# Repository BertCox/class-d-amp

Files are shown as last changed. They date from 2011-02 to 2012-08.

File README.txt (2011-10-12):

File: README.txt
Description: Project-specific instructions and information concerning files
    located within this hierarchy and subhierarchies. In the event of
    conflicts, the lowest-level README.txt file is used for information
    regarding a file or files.

Current Location: ClassDAmp/

Description:
    The Class-D Audio amplifier is an audio amplifier based on the 2004 Sorensen
audio amplifier design (http://listen.to/audioexperiment). The amplifier is able
to provide 100 watts RMS power spread across 2 stereo channels (50 watts RMS each)

Contents:
    Included in this repository are the source files and documentation
necessary to recreate the Class-D audio amplifier. If you believe something is 
missing from the project, please contact us at http://nbitwonder.com/blog/contact

Documentation:
    Documentation related to this project is included in the 'Documentation'
folder. For additional documentation and other information, please see:
http://nbitwonder.com/blog/projects/class-d-audio-amp/

License Information:
    NBitWonder projects are released under the GNU GPL v3.0 for software,
firmware, simulations, and documentation and Creative Commons CC-BY-3.0 
for electronics and mechanical components. License copies can be found in the
file 'license.txt' in each of these top-level folders.
    NBitWonder projects may use files, software, libraries, etc. which is not
open source. These components may not be distributed within the project
repository or use a different license than that specified in license.txt. In
these cases, acquisition instructions and license exceptions are noted in a
given hierarchy's 'README.txt' file. Where conflicting, the lowest-level
'README.txt' file shall apply to a given file or files.

Ben Laskowski
Chief Technical Officer
NBitWonder, LLC

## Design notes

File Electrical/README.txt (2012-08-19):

File: README.txt
Description: Project-specific instructions and information concerning files
    located within this hierarchy and subhierarchies. In the event of
    conflicts, the lowest-level README.txt file is used for information
    regarding a file or files.

Current Location: ClassDAmp/Electrical

Notes:
    This directory contains the following files:
    Version 3.0:
	* single-supply-bridged schematic and layout: The most recent version of 	  the circuit, and the only supported version.
    Version 2.0:
        * single-supply-bridged schematic and layout: 50W max output, questionable 	  speaker protection circuit
    Version 1.0:    
        * class-d-amp-single-supply schematic and pcb: An untested lower-output
          version, appx. 15W per channel
        * class-d-amp-3-5-mm sch/pcb: A dual-supply version, 25W per channel max.
          Not recommended for construction.
        * class-d-amp sch/pcb: The original board layout. Self-destructed during
          first test. Do not build.

Software:
    All electronic design files were created using EagleCAD v5.11 from CADSoft. 
A freeware copy of this software, as well as additional information about this 
software, can be found at http://www.cadsoftusa.com/

License:
    All electronic CAD design files contained within this hierarchy, except those
noted in the 'Exceptions' section below, are made publicly available via a 
Creative-Commons CC-BY-SA 3.0 license. For more information on the license, see 
http://creativecommons.org/licenses/by-sa/3.0/
    Additionally, a complete copy of the license text can be found in the file
'license.txt' distributed within this folder.

Exceptions:
    The following alternative licensing requirements apply to the following files:

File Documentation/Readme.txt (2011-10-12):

File: README.txt
Description: Project-specific instructions and information concerning files
    located within this hierarchy and subhierarchies. In the event of
    conflicts, the lowest-level README.txt file is used for information
    regarding a file or files.
            
Current Location: ClassDAmp/Documentation

    NBitWonder's open documentation system follows the guidelines written 
in our documentation tutorial, which can be found at:
	 http://nbitwonder.com/2010/11/09/becoming-a-better-maker-documentation/

Documents included are:
	1)  Project Overview
	2)  Project Notebook
	3)  Theory of Operation
	4)  Bill of Materials (BOM)
	5)  Construction Guide
	6)  User Manual
    
License:
	All macros and documentation templates are provided under the GNU GPL 
v3.0. A full copy of the GNU GPL v3.0 can be found at: 
    http://www.gnu.org/copyleft/gpl.html
    Additionally, a copy of the GNU GPL v3.0 should be included in the file
license.txt.
	All documentation produced by NBitWonder is the copyright of NBitWonder.
In addition, NBitWonder and the NBitWonder logo are trademarks of NBitWonder
and their use is strictly prohibited except by express written permission 
from NBitWonder, LLC.

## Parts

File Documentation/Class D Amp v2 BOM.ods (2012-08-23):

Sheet: BOM
 |  |  |  |  | Document: | Bill of Materials
 |  |  |  |  | Last Modified: | 10/10/2011
 |  |  |  |  | Project: | Class-D Amplifier
 |  |  |  |  | Project Version: | 2.0
Class D Amplifier
Description | ID | Qty | Value | Package | Manufacturer | Mfg. Part # | Supplier | Supplier Part #
 | C1/C3/C11/C13/C15/C17 | 6 | 1 uF | 0603 |  |  | DigiKey | 490-1536-1-ND
 | C2/C4/C23:C24 | 4 | 820 pF | 0603 |  |  | DigiKey | 490-1493-1-ND
 | C5 | 1 | 10 uF | 0805 |  |  | DigiKey | 445-3458-1-ND
 | C6:C7 | 2 | 270 nF | 1206 |  |  | DigiKey | 490-1777-1-ND
Ripple Capacitor | C8:C9 | 2 | 3300 uF | 7.5x18mm |  |  | DigiKey | 565-1592-ND
5v Bulk Capacitor | C10/C25 | 2 | 100 uF | 2.5x5mm |  |  | DigiKey | P11181-ND
 | C12/C14/C16/C18/C19:C22 | 8 | 100nF | 0603 |  |  | DigiKey | 445-1324-1-ND
 | R1/R5/R7/R11/R20 | 5 | 30 k | 0603 |  |  | DigiKey | P30KGCT-ND
 | R2/R4/R8/R10/R13:R14/R19/R21:R29 | 16 | 2.2 k | 0603 |  |  | DigiKey | P2.2KGCT-ND
 | R3/R9 | 2 | 1 M | 0603 |  |  | DigiKey | P1.0MGCT-ND
 | R6/R12/R17:R18 | 4 | 220 | 0603 |  |  | DigiKey | P220GCT-ND
Resistor | R15:R16 | 2 | 10k |  |  |  | DigiKey | P10KGCT-ND
Output Inductor | L1:L2 | 2 | 33 uH | 12.3x12.3mm |  |  | DigiKey | 308-1337-1-ND
Quad JFET 3MHz | IC1 | 1 |  | SOIC14 | Texas Instruments | TL084CDR | DigiKey | 296-1285-5-ND
Comparator | IC2:IC3 | 2 |  | SOIC8 | ON Semiconductor | LM311DR2G | DigiKey | LM311DGOS-ND
Quad 2:1 XOR Gate | IC4 | 1 |  | SOIC14 | Texas Instruments | SN74HC86DR | DigiKey | 296-8374-5-ND
IC Voltage Regulator | IC5 | 1 |  | TO-220 | Murata Power Solutions | OKI-78SR-5/1.5-W36-C | DigiKey | 811-2196-5-ND
Transistor Gate Driver | IC6:IC9 | 4 |  | SOIC8 | Microchip Technology | MCP14628-E/SN | DigiKey | MCP14628-E/SN-ND
Quad Comparator | IC10 | 1 |  | SOIC14 | Texas Instruments | LM339D | DigiKey | 296-1013-5-ND
Tristate buffer | IC11 | 1 |  | SOIC14 | ON Semiconductor | SN74LS126ADR | DigiKey | MC74HC126ADGOS-ND
Power MOSFET | M1:M8 | 8 |  | TO-252-3 | Zetex Corporation | DMN4009LK3-13 | DigiKey | DMN4009LK3-13DICT-ND
Speaker/Power Terminal | JP1:JP3 | 3 |  |  |  |  | DigiKey | ED2635-ND (phillips) or A98159-ND (slotted)
3.5mm Audio Jack | J1 | 1 |  |  |  |  | DigiKey | CP-3524NG-ND

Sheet: Config
AtomicBOM Configuration Data:
Parameter | Description | Default Value | Value
maxResults | Maximum number of results to display for part searches (integer) | 5 | 5
maxSuppliers | Maximum number of suppliers to display for part searches (integer) | 5 | 5
suppliersInclude | List of suppliers to include in search results (comma separated list)
suppliersExclude | List of suppliers to exclude in search results (comma separated list)
filterROHS | Return only ROHS compliant parts (1: yes, 0: no) | 0 | 0
cacheParts | Cache part data for more efficient future searches (1: yes, 0: no) | 0 | 0
getDatasheetURLs | Return/embed datasheet URLs, if they exist (1: yes, 0: no) | 1 | 1
getSupplierURLs | Return/embed supplier URLs, if they exist (1: yes, 0: no) | 1 | 1
logging | Enable log information for macro (1: yes, 0: no) | 1 | 1
logFile | Filepath to program log file (string)
logLevel | Number corresponding to logging intensity (0-4) | 2 | 2
bundleParts | Bundle parts from single supplier (reduce shipping costs) | 0 | 0
minBundle | Minimum order (dollar value) for part bundling
versionCheck | Check for new versions of AtomicBOM macro suite | 0 | 0
versionURL | AtomicBOM updated version URL
bomVer | Current version of AtomicBOM macro | 0 | 0

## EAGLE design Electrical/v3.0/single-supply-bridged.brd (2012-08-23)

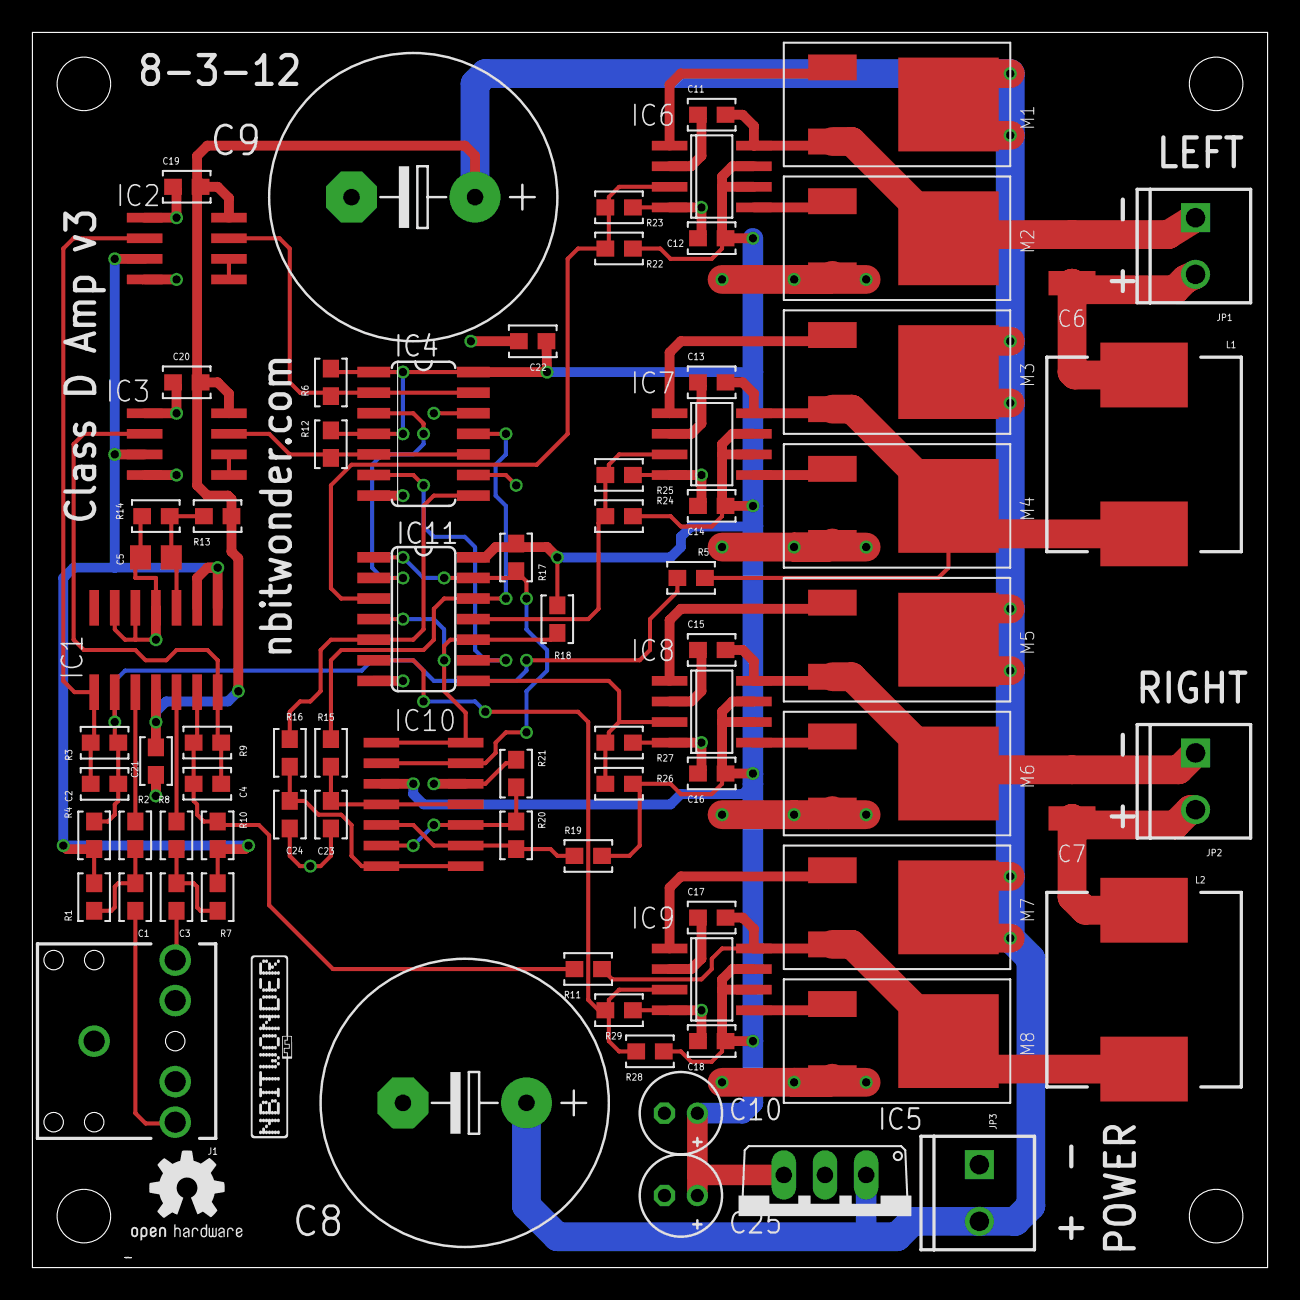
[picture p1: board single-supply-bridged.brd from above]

Board: 2 copper layers, 76.2 x 76.2 mm, 85 parts (0 on the bottom side), 51 nets.

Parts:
C1, C3, C11, C13, C15, C17: 1u; 0603
C2, C4, C23, C24: 820p; 0603
C5: 10u; C0805
C6, C7: 270n; C1210K
C8, C9: 3300u; E7,5-18
C10, C25: 100u; E2-5
C12, C14, C16, C18, C19, C20, C21, C22: 100n; 0603
GOLD_ORB_SM1: OSHWLOGO_GOLD_ORB_SM; OSHW2
IC1: TL084D; SO14
IC2, IC3: LM311D; SO08
IC4: 74HC86D; SO14
IC5: 7805TV; TO220V
IC6, IC7, IC8, IC9: MCP14628; SO-08
IC10: LM339D; SO14
IC11: 74LS126D; SO14
J1: AUDIO-JACKPTH; AUDIO-JACK
JP1, JP2, JP3: SCREWTERMINAL-3.5MM-2
L1, L2: 33u; CDRH125
M1, M2, M3, M4, M5, M6, M7, M8: DMN4009LK3; TO252-3L
R1, R7: 15k; 0603
R2, R4, R8, R10, R13, R14, R19, R21, R22, R23, R24, R25, R26, R27, R28, R29: 2.2k; 0603
R3, R9: 1M; 0603
R5, R11, R20: 30k; 0603
R6, R12, R17, R18: 220; 0603
R15, R16: 10k; 0603
U$1, U$2, U$3, U$4: STAND-OFF
U$5: NBW_LOGOSMALL; NBW_LOGO

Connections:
+5V: C10.+, C12.2, C14.2, C16.2, C18.2, C22.1, C25.+, IC4.1, IC4.4, IC4.14, IC5.3, IC6.6, IC6.7, IC7.6, IC7.7, IC8.6, IC8.7, IC9.6, IC9.7, IC10.3, IC11.14, R6.2, R12.2, R17.2, R18.2, R19.1, R22.2, R24.2, R26.2, R28.2
+12V: C8.+, C9.+, C19.2, C20.2, C21.1, IC1.4, IC2.8, IC3.8, IC5.1, JP3.2, M1.2, M3.2, M5.2, M7.2, R13.2
DCLL: IC1.3, R2.2
DCLR: IC1.5, R8.2
GND: C5.2, C8.-, C9.-, C10.-, C12.1, C14.1, C16.1, C18.1, C19.1, C20.1, C21.2, C22.2, C23.2, C24.2, C25.-, IC1.11, IC1.12, IC1.13, IC2.1, IC2.4, IC3.1, IC3.4, IC4.7, IC4.9, IC4.12, IC5.2, IC6.4, IC7.4, IC8.4, IC9.4, IC10.12, IC11.7, J1.1, JP3.1, M2.3, M4.3, M6.3, M8.3, R14.1, R21.2, R23.2, R25.2, R27.2, R29.2
LGATE: IC10.2, IC10.13, IC11.1, IC11.13, R17.1
unnamed: C11.1, IC6.2
unnamed: C1.2, R1.1, R2.1
unnamed: C6.1, C11.2, IC6.8, JP1.1, M1.3, M2.2
unnamed: IC6.1, M1.1
unnamed: IC6.5, M2.1
unnamed: C13.2, IC7.8, L1.1, M3.3, M4.2, R5.2
unnamed: C13.1, IC7.2
unnamed: IC7.1, M3.1
unnamed: IC7.5, M4.1
unnamed: IC4.3, IC11.2
unnamed: C1.1, J1.5
unnamed: C15.1, IC8.2
unnamed: IC2.5, IC2.6
unnamed: IC8.1, M5.1
unnamed: IC8.5, M6.1
unnamed: IC6.3, IC11.3, R22.1, R23.1
unnamed: C3.1, J1.2
unnamed: C2.1, IC1.2, R3.1, R4.2, R5.1
unnamed: C2.2, IC1.1, IC2.2, R3.2
unnamed: C17.1, IC9.2
unnamed: C17.2, IC9.8, L2.1, M7.3, M8.2, R11.2
unnamed: IC9.1, M7.1
unnamed: IC9.5, M8.1
unnamed: C7.2, JP2.2, L2.2
unnamed: IC2.7, IC4.2, IC4.13, R6.1
unnamed: C6.2, JP1.2, L1.2
unnamed: C24.1, IC10.7, IC10.8, R16.2
unnamed: C23.1, IC10.4, IC10.11, R15.2
unnamed: IC3.5, IC3.6
unnamed: IC7.3, IC11.11, R24.1, R25.1
unnamed: IC3.7, IC4.5, IC4.10, R12.1
unnamed: C3.2, R7.1, R8.1
unnamed: IC8.3, IC11.8, R26.1, R27.1
unnamed: C4.1, IC1.6, R9.1, R10.2, R11.1
unnamed: C4.2, IC1.7, IC3.2, R9.2
unnamed: C7.1, C15.2, IC8.8, JP2.1, M5.3, M6.2
unnamed: IC4.6, IC11.9
unnamed: IC9.3, IC11.6, R28.1, R29.1
unnamed: C5.1, IC1.10, R13.1, R14.2
PWML: IC4.11, IC11.12, R15.1
PWMR: IC4.8, IC11.5, R16.1
RGATE: IC10.1, IC10.14, IC11.4, IC11.10, R18.1
VCCINT: IC1.8, IC1.9, IC2.3, IC3.3, R1.2, R4.1, R7.2, R10.1
VRHI: IC10.5, IC10.9, R19.2, R20.1
VRLO: IC10.6, IC10.10, R20.2, R21.1

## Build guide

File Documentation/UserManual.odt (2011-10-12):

User Manual

Project: ProjectName

Date: ManualDate

# 1.0. Introduction

Briefly describe the product, it's purpose, it's function. Describe the items that should have come with the product (all boards, SD card, batteries, etc.). Describe any complementary items that can be used with the product (accessories, etc.)

# 2.0. Usage Information

Information related to the usage of the project. Describe any assembly information needed for this project (if the project doesn't come fully assembled). Detail navigation through any and all software menus. Describe important basic procedures, such as changing the batteries or replacing the SD card.

# 3.0. Safety Information

Their may be some relevant safety issues for your project that users should know. Some are very trivial (choking hazard, keep away from water). Some may be special information relevant to your product (example: if your product contains a laser, a warning about not pointing it in a person's eyes is probably reasonable)

# 4.0. Care Information

Information about maintaining a product. This section might contain information about replacing the batteries, or conditions for storage (ex. store in a cool, dry place). Additionally, any disposal or recycling instructions should be included here.

# 5.0. Support Information

Technical support and other relevant information. This section might include frequently asked questions or common troubleshooting steps. Also, add any contact information (email, website, phone) for additional support information for your product.

# 6.0. Legal Information

Some types of products and equipment may have important legal considerations related to their use (example: for recording equipment, recording private conversations as a third-party is illegal in many states). Provide the user with any important legal information to help keep them, and your company, safe from lawsuits. Additionally, consider adding licensing information (even if you're using an open license) in this section. If your product is to have a warranty, this section is where you'll want to include that.

http://nbitwonder.com 2 [Insert Copyright etc. here]

http://nbitwonder.com 2 ©2011 NBitWonder LLC

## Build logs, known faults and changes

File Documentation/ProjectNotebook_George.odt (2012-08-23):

Project Notebook

Project: Class-D Amp

Author: George Hadley

I began constructing my own copy of the NBitWonder Class-D amplifier project designed by Ben today. For the most part, the amplifier is a fantastic project, and as our first “complete” project, has the greatest potential to be a commercially-sellable project for NBitWonder, brining in revenue. That said, however, there are a few improvements to the amplifier that could/should be made. The improvements include:

Entry: 001 Time: 12/05/2011 21:03 UTC Version: 2.0 Title: Class-D Amp v2.0 Improvements

1. Correction of IC silkscreen layer error for ICs 1, 2, and 3
2. Taking advantage of the silkscreen layer on the backside of the board to include a large NBitWonder logo, voltage/power/current information, etc.
3. Reducing the size of the onboard capacitors, to reduce the overall board envelope
4. Improvements to the end-user power and audio connections. The use of a barrel jack and laptop power supply or some other connection option would be extremely ideal. For speakers, quick connections could/should be made, using a set of speaker terminals, such as those found here (http://www.amazon.com/American-Terminal-AT-TC-1-Speaker-Square/dp/B001762LHQ).
5. Inclusion of a power indicator led, and possibly one or more debugging/status leds as well.
6. Adjustments to the onboard 5V regulator to do away with the need for the heatsink.

I started a forum thread for these and other improvements, which can be found here (http://nbitwonder.com/forum/viewtopic.php?f=12&t=70).

Ben Laskowski Class-D Amp Project Notebook

http://nbitwonder.com ©2011 NBitWonder LLC

http://nbitwonder.com 1 ©2011 NBitWonder LLC

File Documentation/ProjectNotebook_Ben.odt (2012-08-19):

Project Notebook

Project: Class-D Amp

Author: Ben Laskowski

After the overwhelming success of the Class-D audio amplifier, it was decided to pursue an improved, less experimental version. Some ideas for the revised circuit include using entirely surface mount parts (reduced size and potentially increased performance), a higher supply voltage (increased power output), and an output inductor with a lower series resistance. Other ideas brought forward for consideration are the use of a different class, such as Class G, Class H, Class I, or Class T. These ideas were rejected due to potential copyright/patent issues and complexity.

Entry: 001 Time: 1/27/2011 05:42 UTC Version: 1.0 Title: Defining Requirements

This post is duplicated from the NBitWonder Forums.

Entry: 002 Time: 1/29/2011 05:44 UTC Version: 1.0 Title: Initial BOM

After some research, I've arrived at a partial bill of materials.

- MOSFETs – DMN4009
- Gate driver – IRS2004
- Comparator – LM311
- Integrating error amp - TL082

The amplifier will, like the prototype, be a self-oscillating type. My hope is that with proper construction techniques, the operating frequency will be quite high, ideally upwards of 500kHz. To that end, the output filter has been designed as a second-order Butterworth filter with a cutoff of 50kHz when operated with an 8-ohm speaker, a common value for home use. An inductor has been identified with a very low series resistance, which should help efficiency improve over the prototype.

The MOSFETs selected for use this time are cheaper than the IRL520Ns used last time and have a much lower on-state resistance, which should lead to increased efficiency. The MOSFET gate driver is cheaper than the one used for the experiment, but supports a lower drive current and a lower maximum voltage - but at the voltages slated for use in this project, this becomes a non-issue.

The input stages (TL082 and LM311) are slated to be unchanged from the previous iteration, since the parts are already low-cost and well-suited for the task at hand.

Expected power output, based on a +/-18V supply and an 8-ohm speaker, is 18^{2}newline overline {8*2} = 20W RMS under ideal conditions. Peak power (I.e, turning on one MOSFET or the other and allowing the output filter to reach steady state) is arrived at with V^2 newline overline{R} ; the extra factor of 2 converts peak power to RMS. To support this power output, the power supply should be capable of delivering sqrt{stack{20W # overline {8*omega}}} = 1:58 amps per channel.

Today saw significant work on PCB layout.

Entry: 003 Time: 1/30/2011 05:58 UTC Version: 1.0 Title: PCB Layout 1

The PCB layout was finished today. A secondary version was created that features RCA input jacks instead of the more compact and lower cost 3.5mm stereo minijack.

Entry: 004 Time: 1/31/2011 06:00 UTC Version: 1.0 Title: PCB Layout 2

While waiting for the PCBs to come in, I worked on the breadboarded prototype a little bit. I discovered that by changing the resistor and capacitor in the integrating feedback loop to 1M and 0.001uF respectively, power output increased greatly before audible distortion set in. Thankfully, implementing this on the PCB does not require any changes in the layout.

Entry: 005 Time: 3/05/2011 06:01 UTC Version: 1.0 Title: Prototype Tweeks

Today, I constructed a duplicate amplifier circuit on the breadboard to have stereo capability,

Entry: 006 Time: 3/06/2011 06:02 UTC Version: 1.0 Title: Continued Prototype Work

making sure to incorporate the changes from yesterday. Testing with my laptop as a signal source produced good results, though it seems that clipping sets in at a lower level now. My theory as to the cause is that the power supply I am using for testing cannot supply enough current to run both stereo channels at a high volume simultaneously.

With the 'laptop test' complete, I moved the amp to the living room to try it with my TV. Upon powering on the circuit, a loud 60Hz buzz permeated the room. It was determined that the cause of the buzz was a ground loop { the TV and amp were both grounded, and the signal cable between them also had a ground connection. Removing the AC ground from the power supply used on the amplifier solved the problem by eliminating all directly-connected paths between the two circuit grounds.

The PCBs arrived today!

Entry: 007 Time: 3/10/2011 06:04 UTC Version: 1.0 Title: PCBs Arrive

Rather than dive right in with their assembly, though, I decided to spend some time focusing on the amplifier's packaging. As this is an area I have yet to pay any real attention to on any of my projects, I thought it appropriate to make it a priority for this project. A brief trip to Radio Shack left me with some 4-40 mounting hardware (nuts, bolts, and washers), a 3x5x7 inch plastic project enclosure, a panel-mount audio input jack, and spring-loaded speaker terminals. A few hours spent with a Dremel tool left me with suitably sized holes in the enclosure.

Today saw much of the amplifier's power supply assembly. The transformer was mounted in the case, along with the power switch, fuse, and line input cord. The appropriate connections were soldered, and the supply was tested. The 24V center-tapped transformer that was selected for this build produced a no-load voltage of 13.6VAC from the center tap to each end of the secondary winding. As this voltage when rectified and filtered will exceed the voltage limits of at least one of the analog components, it may be necessary to drop the voltage slightly with diodes or an add-on regulator if the voltage does not drop appreciably under load.

Entry: 008 Time: 3/11/2011 06:06 UTC Version: 1.0 Title: Power Supply Assembly

I also began assembling the main amplifier PCB, but was forced to an abrupt end when I discovered that I made a mistake in the parts order, procuring one too few comparator and the wrong value of output filter capacitors. A parts order was placed with Newark for the missing components.

The PCB was built up to the extent possible today. Still not populated are the various input and output connections (as these are more easily done once mounted in the case), the power filtering capacitors (as they are large and would likely impede access to the smaller-footprinted components).

Entry: 009 Time: 3/12/2011 06:08 UTC Version: 1.0 Title: PCB Assembly Work 2

In light of the unexpectedly high transformer secondary voltage discovered yesterday, some work was done to identify a better way of powering the amplifier. An inexpensive switchmode controller, the AP34063, was found to be a sub-one-dollar solution to the problem. In a future revision of the amplifier, a single-ended supply of up to 40VDC (or 28VAC followed by a rectifier) will be applied to the amplifier PCB and sent directly to the output MOSFETs. This input voltage will also pass through a low-current switchmode regulator centered on the aforementioned AP34063 which will generate a 12VDC control supply to operate the input stages and MOSFET gate driver IC. This will allow for a greater supply voltage, boosting output power; additionally, the power supply requirements will be greatly relaxed.

An initial design was drawn up for the single-supply amplifier. It is now included in the github repository for the project, though it is far from done.

Entry: 010 Time: 3/13/2011 06:11 UTC Version: 2.0 Title: Single-Supply Amplifier (amp v2)

Some work was done on component placement for the single-supply board layout. Additionally, the MCP14628 was identified as a potential gate driver for the new amplifier version. It is similar to the IRS2004 currently in use, but with much lower propagation times between a gate command on the input and an action on the output. Its deadtime is variable and is automatically configured based on the characteristics of the attached MOSFETs, which is far ahead of the fixed 520ns deadtime on the IRS2004. It has been added to the Eagle library.

Entry: 011 Time: 3/14/2011 06:13 UTC Version: 2.0 Title: Single-supply amplifier progress

The downside of using the MCP gate driver is the limit on its bootstrap voltage pin – 35v. This means that the supply to the amplifier cannot exceed 30VDC, limiting power output to approximately 15W. If the output sound quality is better, though, this is probably an acceptable tradeoff to make. Otherwise, a similar part from National Semiconductor exists – the LM5104 – but its cost is about double the MCP part at roughly 3 dollars.

More work was done with regard to component placement on the single-supply version of the amplifier tonight. It is believed that component placement is now final, more or less. Additionally, an experiment was conducted with bridging mode on the breadboard. Recognizable sound was emitted from the speaker, but it was highly distorted. It is believed at this time that the output filter's capacitor was connected between the positive speaker lead and the then-irrelevant ground instead of across the speaker terminals. Further tests will be conducted as time allows.

Entry: 012 Time: 3/16/2011 06:16 UTC Version: 2.0 Title: Single-supply amplifier progress 2

Another version of the single-supply layout is in progress, too. This secondary version features bridged outputs for each channel, allowing a theoretical 56W output per channel with a single-ended 30V supply. If further breadboard tests with bridging (and eventually, single- supply bridging) are successful, this PCB layout will be furthered. For now, it will be set aside.

The missing parts for the dual-supply amplifier prototype arrived yesterday. Unfortunately, I rushed through the order process last week and requested the DIP-8 version of the LM311 instead of the SOIC-8 version. Another order was placed and should hopefully arrive shortly. Once I finally have a part with the correct footprint, this amplifier should come together very quickly. I was, however, able to solder down the new filter capacitors, so that is done.

Entry: 013 Time: 3/19/2011 06:19 UTC Version: 1.0 Title: Progress on Amplifiers

I spent some more time working on the single-supply amplifier layout. It is now complete – at least as a first draft – and has been placed in the git repository.

The replacement comparators arrived today, and they were installed. The board then had its final components added and peripheral connections to the case-mounted connectors completed. A brief power-up test revealed that nothing major was wrong. The MOSFET gate drivers were running quite warm, but they were within specs outlined in the datasheet. The power supply was measured to be a bipolar 19VDC for 38VDC total across the entire board. The expected value was more like 33V, but this was deemed to be within spec due to the lightly-loaded power transformer.

Entry: 014 Time: 3/22/2011 06:21 UTC Version: 1.0 Title: Magic Smoke

The amplifier was then connected to a signal source (my TV) and speakers for its first real test. The amplifier performed flawlessly for several minutes, but then suddenly ceased to function and simultaneously sent a large amplitude 60Hz buzz to the speakers. Subsequent disassembly revealed a "burnt component" smell and a MOSFET solder joint that appears to have been reflowed.

The hypothesized failure mode is that a brief power glitch on the AC mains (due to my refrigerator turning on at the exact moment of amplifier failure) temporarily boosted the amplifier supply voltage sufficiently to over-volt the gate of the MOSFET – which has a maximum Vgs of 20V – and permanently short it. This would explain the 60Hz hum of the power supply being directly coupled to the speakers as the transformer struggles to boost the output voltage to its designed operating point. At this time, it is believed that replacing the power transformer with a lower-voltage output model and replacing the damaged MOSFET will fix the problem with this particular amplifier build.

As time allows, development will continue on the single-supply version of the amp. It is believed that by regulating a few crucial control voltages, disasters like tonight's can be avoided in the future. Until the amplifier failed, its output sound quality was noticeably better than the breadboaded version of the amplifier, implying that the basic is sound and need not be abandoned.

A single-supply amplifier prototype was built up on a breadboard today. After much tweaking of the feedback network to ultimately include a DC-blocking capacitor and adding a second gate driver and half-bridge driven 180 degrees out of phase with the first, a single-supply bridged amplifier is now functional.

Entry: 015 Time: 4/04/2011 22:22 UTC Version: 2.0 Title: Single-supply Amplifier

Since its modulator is driven from 5v (instead of 12v-15v as in the dual supply version), I was able to connect a logic analyzer to the generated PWM signal. The switching frequency using reasonably compact construction techniques is approximately 250kHz.

It was found that operating the amplifier near peak volumes from the signal source (an iPod) creates issues with MOSFET gating that may temporarily short-circuit the power supply. This will have to be addressed before a production version is completed – but it is believed that switching to the new gate driver with much shorter dead times should improve this. Schematics and updated board layouts will follow as time allows.

Some more experimentation was carried out with the breadboarded bridged single-supply amplifier. It was determined that – unexpectedly – using a 13V supply produced louder output than a 26V supply. I hypothesize that this is due to the feedback network and its (surprise!) 13:1 ratio between output and feedback. Changing this to something along the lines of 26:1 or 30:1 should boost output at higher supply voltages.

Entry: 016 Time: 4/04/2011 23:24 UTC Version: 2.0 Title: Single-supply Amplifier 2

I also read up on ways to improve the noise performance of the amplifier. The LM311 comparator datasheet offered a number of suggestions for making its output transitions faster and more decisive (so to speak), which involved shorting two adjacent but otherwise unconnected pins on the IC. This was done on the breadboard and it seems to help ever so slightly. Additionally, the datasheet suggests placing a small capacitance directly between the comparator input pins. A footprint for a suitable cap will be included on the next PCB revision, though the part may not be populated.

I worked on the single-supply bridged layout some more this evening. Upon realizing that the board was nearly twice the size of the previous revision, I made the executive decision to replace the switching regulator with a linear regulator to save considerable board space. This should be an acceptable tradeoff, since the average current draw on the 5V rail will be on the order of 50mA - 100mA. Large current spikes will be drawn for 40-50ns while the output devices switch, but this will be twice every 4us, for a duty cycle in the sub-one-percent range. Since the maximum input voltage is limited to 30V by the gate driver anyway, this does not deprive us of output power.

Entry: 017 Time: 4/06/2011 22:26 UTC Version: 2.0 Title: Bridged Single-Supply Analysis

I also made some headway on boosting power output at higher supply voltages. Replacing the 1k resistor in the feedback network with a 560-ohm resistor seems to have made all the difference. I can now advance the input volume quite far before the onset of clipping. If my understanding of the circuit is correct, this reduces the amount of the output signal that is integrated with each cycle, allowing the current in the filter inductor to increase to a higher value and drive more power through the speaker.

On the topic of last weekend's tests that resulted in shorting the power supply, it is now believed that the inductor was entering saturation. On average, the output voltage is zero (as is the inductor current). HOWEVER, the inductor current can rise to two or three amps during the highest part of the modulating waveform. Suppose for instance the H-bridge is currently conducting such that 26V is across the output. If the capacitor voltage is 0 and the switching frequency is 250kHz (typical measured values), the inductor current increases to 2.8A near the end of the switching cycle, which is the saturation current for the chosen inductor. An inductor in saturation is characterized by an increase in current with no corresponding increase in flux – so it looks like a dead short. At least, this is what I think the amp was doing last weekend.

Having recently acquired a basic oscilloscope, I was able to take a few measurement concerning the amplifier's operation. For a 0.560Vpp input, the amplifier produces an output of 19.2Vpp. For this test, the input signal was a 1kHz sine wave from my computer sound card.

Entry: 018 Time: 4/07/2011 22:26 UTC Version: 2.0 Title: Bridged Single-Supply Analysis

I was also to determine the point at which the amplifier starts clipping – the point that corresponds to the maximum output power with good sound quality. This point occurs at 20Vpp, or at 10V on either side of the neutral point, with a 26V supply. Because the output stage is an H-bridge, this corresponds to a duty cycle of 0.69 from the output of the comparator for the positive peak of the clipping waveform. Additionally, 10V across the speaker corresponds to a load current of 1.25A. The ripple current through the load at this point can be determined as follows:

We know that the voltage across the inductor can be expressed as (Vsupply - Vout), or here, 16V. The voltage across an inductor can be expressed as VL = L di slash dt . Rearranging and solving for dt, we arrive at underline {V_{L}dt} newline L = di. Here, dt is the time in which voltage is rising, or the product of the duty cycle k and the switching period Ts, so di = underline {V_{L}kT_{s}} newline 2L , since the total current rise is twice the ripple current. Substituting our circuit parameters, we arrive at a ripple current of 0.67A. Adding this ripple value to the average value for this point gives a maximum inductor current of 1.92A, which approaches the saturation value of 2.3A for the inductor in use in the circuit.

The other explanation is that my power supply is underpowered for this application. The supply is capable of a bipolar 13V output unloaded, and the transformer is rated for some 800mA. As an experiment, I connected an 8-ohm resistor between its 13V terminal and its ground terminal, and the output voltage dropped from 13.2V to 8.72V. This may partially explain the difficulty I am seeing. I will try to find a more powerful supply in the 26V range for further testing. (I have a couple of supplies capable of high current at 12V, but I'd really like to test the amp near the edge of its range to hopefully foresee any self-destruction problems like the ones previously experienced.)

Oscilloscope screen captures to follow.

I replaced the inductor I had been testing with (which saturates at 2.3A) with one used on a previous project. The replacement inductor has a saturation current of 4.9A. Sadly, the low-voltage clipping and temporary power supply shorting behaviors remain. I would like to blame transistor dead times, but I have no good way to prove this at present.

Entry: 019 Time: 4/08/2011 22:42 UTC Version: 2.0 Title: New Inductor

A lot of amp work was done today. First, I hooked up the logic analyzer to the gating command signals (from the comparator) and to the bottom MOSFET gates. The upper gates were not included due to their need for a floating supply and the 5V maximum input of the logic analyzer. It was discovered that at high input levels, the bottom MOSFET on a given channel would turn itself on while the top MOSFET was conducting, leading to the shoot-through condition. I tried to stop this from happening by placing reverse-biased high-speed diodes between the source and drain of each MOSFET, but this did not solve the problem. It may be necessary to get a "stronger" gate driver that can sink multiple amps of current to keep transistors turned off when they're supposed to be off.

Entry: 020 Time: 4/09/2011 22:43 UTC Version: 2.0 Title: Changing the analog front end

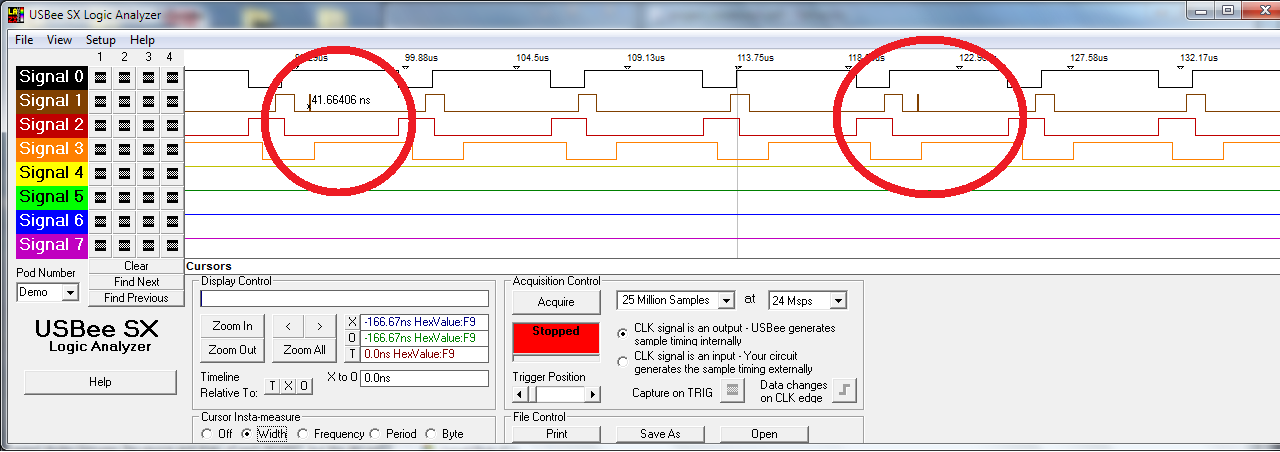
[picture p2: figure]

Fig. 1. Transistor Switching Error

Noticing that the amp could become unstable at times with the DC blocking capacitor in the feedback loop, I rewired the analog front end to eliminate the need for this capacitor. Instead of powering the input op-amp and comparator o of 5V as I had been doing, I now power them off of the full input voltage. The input is limited to 30V by the gate driver, so no specs should be exceeded in doing this. Additionally, the comparator output is open-collector, so logic level interfacing between the gate driver and comparator is done inherently and no special attention is needed to accomplish it. A second op-amp channel is still used to create an internal low-current Vcc/2 rail, but this rail now operates at half the supply voltage instead of 2.5V.

A new problem was introduced, though. If the requested output is greater than what the MOSFETs can supply for any period of time, the amplifier can stop oscillating. Luckily, the failure mode happens such that one half-bridge stops conducting completely, so a speaker- destroying DC current does not appear across the speaker. This issue will have to be dealt with prior to ordering amplifier PCBs. One potential correctional measure is to include an additional triangle-wave based modulator.

I spent some time today reviewing the gating circuitry for the MOSFETs. It dawned on me that one of the gate drivers was driven with an open-collector signal (so there was a pull-up resistor in the signal path, leading to potentially slow turn-on times) and the other was driven with a push-pull signal from an inverter. To equalize the two delays, two XOR gates were used. The open-collector signal connects to both 'A' inputs. The first gate's 'B' input is connected to 0v to make a pass-through gate, and the second gate's 'B' input is connected to 5v to make an inverter.

Entry: 021 Time: 4/10/2011 22:49 UTC Version: 2.0 Title: More Debugging

Unfortunately, this did not x the problem. The amplifier can still output a negative voltage with a magnitude equal to the power supply voltage, but the positive voltage magnitude is limited to 10V or so.

After much head scratching, I arrived at a breakthrough on the the amplifier clipping problem. I determined that the high-end clipping was due to the "top" MOSFET's bootstrap capacitor running out of charge during prolonged operation with the top switch turned on. This condition manifested itself by having the top MOSFET on the "positive" channel (the one from which feedback is taken) become quite warm and stop conducting during prolonged "on" periods, that is, when the gate drive signal commanded that MOSFET on.

Entry: 022 Time: 4/13/2011 22:51 UTC Version: 2.0 Title: Duty cycle limiter, gate drive mode

To fix this, the bootstrap capacitor value was first increased to 1uF, after which a marked increase in available conduction time was noted... but the problem persisted at times. Rather than increase the capacitor arbitrarily, an alternative solution was developed: a duty cycle limiter.

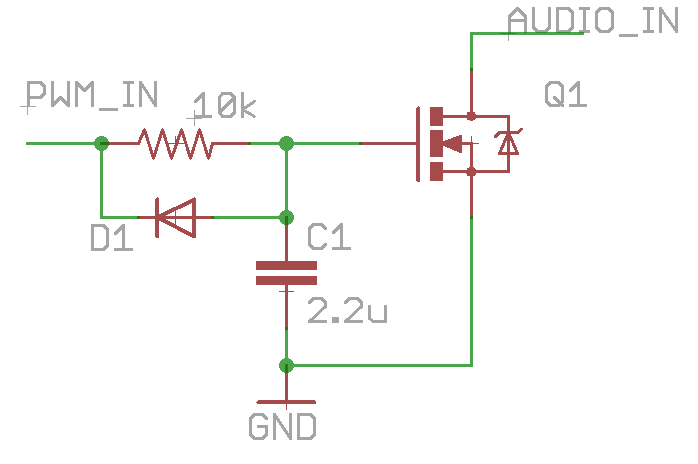
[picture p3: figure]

Fig. 2. Duty Cycle Limiter

The limiter consists of an RC circuit connected to an N-channel MOSFET. The resistor in the RC circuit is connected in parallel with a diode biased such that it conducts only on the "low" edge of a PWM waveform. The circuit's capacitor is connected across the MOSFET's gate and source terminals such that it delays the turn-on of the MOSFET. When the PWM waveform goes high, the capacitor begins to charge via the resistor. If the PWM signal goes low before the MOSFET turns on, the circuit operation is unchanged. If, however, the PWM signal stays high long enough to charge the capacitor, the MOSFET fires and pulls the amplifier channel's audio input to ground via a resistor (not pictured). When this signal goes to ground, the amplifier tries to compensate by reducing the output voltage, turning off the PWM signal and the problem transistor. The duty cycle limited capacitor then discharges, and the circuit automatically resumes normal operation.

It is believed that this circuit will fix nearly every issue this breadboarded prototype has been having. Before ordering a nal PCB, though, I will wait until I've had a chance to validate desired operation of the MCP14628 driver IC, which I hope to use in the new amplifier version due to performance and availability concerns with the old driver.

I put together a simple PCB I laid out based on the MCP14628 synchronous buck driver. The board features the driver, two MOSFETs, and a couple of caps; that's it. It turns out that the gate driver switches sufficiently fast that the breadboarded power supply (with copious decoupling) can't supply sufficient current pulses to operate the switch! That is to say, the circuit sort of works but not really. In order to tell for sure if this new gate driver will work as intended, it will likely be necessary to lay out a PCB for the amp without knowing beforehand if it will work. Hopefully the product, experimental or not, will be ready in time for Maker Faire North Carolina, coming up in about 6 weeks.

Entry: 023 Time: 4/26/2011 22:56 UTC Version: 2.0 Title: New Gate Drivers

I tested the gate driver breakout board some more, and managed to short something out with a slip of the DMM probe while taking measurements. The magic smoke was swiftly released... but the gate drivers appear to do the trick when suitably large reservoir caps are present. Thusly, I began a revised board layout incorporating all the changes made to the breadboarded version.

Entry: 024 Time: 4/28/2011 22:58 UTC Version: 2.0 Title: New Gate Drivers 2

I worked on the revised schematic and board layout today. Thirty-eight airwires remain, down from approximately 160 at the outset of the layout. Hopefully, this layout will be completed this weekend or soon after.

Entry: 025 Time: 4/29/2011 22:59 UTC Version: 2.0 Title: New PCB Layout

Zero airwires achieved! After a peer review, the design will be sent off for fabrication. This should hopefully happen within a couple of days.

Entry: 026 Time: 4/30/2011 23:01 UTC Version: 2.0 Title: New PCB Layout 2

I ordered a copy of the latest PCB revision tonight from Advanced Circuits.

Entry: 027 Time: 5/04/2011 23:02 UTC Version: 2.0 Title: PCBs Ordered

Parts for the newest PCB revision were ordered tonight. Total parts cost (before tax and shipping) was USD 32. Not bad for something that can theoretically produce 50W per channel.

Entry: 028 Time: 5/09/2011 23:03 UTC Version: 2.0 Title: Parts Ordered

Amplifier parts arrived last week, and the PCB arrived yesterday. This could mean only one thing – it was time to assemble the PCB!

Entry: 029 Time: 5/17/2011 23:05 UTC Version: 2.0 Title: Single-supply Amp Assembly

I am pleased to report that assembly went very smoothly, taking approximately 90 minutes to completely populate the board. Once powered up, the amplifier worked beautifully and did not show any tendency to emit smoke. The only complaint I have is that the 5V regulator becomes quite warm under normal operation, but it is my own fault for using a linear regulator in this capacity. A switching regulator would have been much more efficient, but it also would have added to the cost significantly and likely would have degraded audio quality. A small heatsink should fix this problem quite readily.

A demonstration video has been posted to YouTube, and photos of the completed PCB can be found on our Flickr page.

I spent a few minutes revisiting the input networks for the preamplifiers, and found that the blocking capacitor and biasing resistor made a high-pass filter with a cutoff of 72Hz. This could potentially lead to a dropoff in low-frequency response, so the 2.2k resistors were changed to 30k. Similarly, the 2.2k resistors in the duty cycle limiters were changed to 30k to reduce the chances of the network altering the input signal. These are very minor changes and do not require PCB changes.

Entry: 030 Time: 5/30/2011 23:07 UTC Version: 2.0 Title: Minor Schematic Corrections

A plan is afoot to further increase amplifier power output by increasing the value of the feedback resistors.

While I do not have hard and fast data on frequency response or duty cycle limiting (yet?), I am pleased to report that the amplifier produces a full 40W RMS into an 8-ohm load when driven with a 24V power supply. This represents 46.8Vpp across the speaker!

Entry: 031 Time: 8/06/2011 23:09 UTC Version: 2.0 Title: Testing New Component Changes

Last weekend, George was in town. He assembled a latest-revision PCB (from last August) and it worked properly. That's the good news.

Entry: 032 Time: 06/05/2012 01:51 UTC Version:2.0 Title:A Brief Success, and Magic Smoke

Later in the day, the amplifier that had been used as my main TV sound system for the last year suddenly stopped working. It powered on, but quickly became abnormally hot – to the point that it could not be touched during operating. Upon a closer visual inspection, it appears that it got enough to reflow some of the solder joints on the output MOSFETs. I theorize that a gate driver stopped functioning properly, allowing shoot-through to occur on some of the output devices.

As a test, we connected George's amplifier to an iPod and my pair of speakers. Upon power on the amplifier, I saw the center of the woofer's cone move about a half-inch and stay there, indicating a strong DC bias across its voice coil. After this excursion, neither of the woofers functioned any longer. This time, I suspect the amplifier was not oscillating, applying the full 24v continuously across the speakers. Further testing of the speakers showed that only middle- and high-frequency sounds were emitted from them, indicating that the woofers are indeed a lost cause.

After a year of solid service, I am not sure what caused the amplifier to suddenly stop working. It is possible that the power supply (a $13 eBay model) developed a fault, taking the amplifier and speakers with it. It is equally likely that a poor solder joint in one of the feedback circuits caused the amplifier to continuously drive its output to one state instead of oscillating at 250 kHz, as it should. In either case, the amplifier will require either some substantial revision or the addition of a failure protection circuit to prevent such catastrophic losses in the future.

Several ideas to increase the robustness of the design:

- Switch to a triangle-wave-based design instead of self-oscillating
- Replace the existing control circuit with a delta-sigma modulator IC
- Switch to a commercial amplifier IC

Further analysis is needed before any design revisions are made.

After some disappointing amplifier behavior several months ago (namely, a complete failure of the output stages), an updated amplifier protection circuit has been developed. The core of the circuit is a window comparator that is configured to output a gate-enable signal when the commanded PWM signal to the speaker is between 7% and 93% of full scale. This gating signal connects to the control terminal of a 74LS126 that is inserted between the XOR gate outputs and the gate driver inputs. When the PWM drive command is in the allowable range, the window comparator and '126 combination allows the gating commands to pass to the gate drivers unimpeded. When the PWM signal strays outside the allowable range, the PWM drive is disconnected from the gate drivers.

Entry: 033 Time: 08/19/2012 17:10 UTC Version:3.0 Title:Updated Protection Circuit

Here is where the interesting part of the protection circuit comes into play. Careful study of the MCP14628 gate driver datasheet reveals that, when its gating command input is held at half the supply voltage, both output devices are turned off. Since the 74LS126 removes the gating signal when it goes outside the allowable range, the MCP14628 input is allowed to float. In this case, the input is held at half the supply voltage by a resistive voltage divider that has been added to the circuit.

The PWM drive signal is passed through an RC low-pass filter before entering the window comparator to extract the average value of the signal. The cutoff frequency of this filter is 20 kHz, well below the expected switching frequency of the amplifier. In simulations, increasing the PWM drive duty from 0% to 50% enables the gate driver within 1 microsecond. Instantaneously reducing the drive signal duty from 50% to 0% gates the drive signal off after 20 microseconds. The amount of energy transferred to the speaker during this response time is minimal, so this circuit should adequately protect the speakers driven by the amplifier.

Ben Laskowski Class-D Amp Project Notebook

http://nbitwonder.com 7 ©2011 NBitWonder LLC

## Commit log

2011-02-02 Added initial project notebook entries and initial schematics and PCB layouts
    [class-d-amp-3-5-mm.brd, class-d-amp-3-5-mm.sch, class-d-amp.brd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]
2011-02-06 Updated 3.5mm input version to have bridging capability
    [class-d-amp-3-5-mm.brd, class-d-amp-3-5-mm.sch]
2011-03-07 Updated the project notebook to reflect several recent prototype changes
2011-03-14 Updated project notebook and added preliminary schematic for single-supply version of the amplifier
2011-03-14 Added single-supply design files to repository
    [class-d-amp-single-supply.brd, class-d-amp-single-supply.sch]
2011-03-15 Worked on component placement for single-supply amplifier
    [class-d-amp-single-supply.brd, class-d-amp-single-supply.sch]
2011-03-19 Finished draft of non-bridged single supply version
    [class-d-amp-single-supply.brd, class-d-amp-single-supply.sch]
2011-03-23 Project notebook updated to reflect tonight's prototype progress -- or lack thereof
2011-04-05 Added noise suppression devices to comparator circuit -- PCB updates to follow
2011-04-07 Updated notebook with more experiment results and preliminary bridged single-supply layout
    [single-supply-bridged.brd, single-supply-bridged.sch]
2011-04-08 Added measured values for circuit and inductor current analysis.
2011-04-08 Notebook updated with results of power supply loading experiment
2011-04-10 Added information on power supply shorting events and proposed solution
2011-04-14 Update notebook with believed solution to duty cycle and MOSFET drive problems
2011-04-27 Updated project notebook with preliminary results stemming from experiments with the new MCP14628 gate drivers
2011-05-01 Finished updated single-supply bridged layout
    [single-supply-bridged.brd, single-supply-bridged.sch]
2011-05-02 Finished PCB layout, awaiting peer review
    [single-supply-bridged.brd, single-supply-bridged.sch]
2011-05-18 Updated notebook with results of new PCB build
2011-05-30 Updated a few resistor values in the schematic to improve low-frequency response
    [single-supply-bridged.brd, single-supply-bridged.sch]
2011-06-21 Updated schematic for higher output power and better power supply rejection ratio
    [single-supply-bridged.brd, single-supply-bridged.sch]
2011-06-22 Incremental updates -- changed C5 to 0805 package size, changed a few resistor values
    [single-supply-bridged.brd, single-supply-bridged.sch]
2011-08-07 Updated two component values, no other changes
    [single-supply-bridged.brd, single-supply-bridged.sch]
2011-09-25 Added BOM
    [Class D Amp BOM.ods]
2011-10-12 Repository structure cleanup, documentation overhaul
    LaTeX documentation replaced by OpenOffice
    [Class D Amp BOM.ods, Class D Amp v2 BOM.ods, class-d-amp-3-5-mm.brd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]
2012-08-19 Adding version 3.0 of circuit. New version features improved protective circuitry. Simulation of additions added. Notebook updated.
    [single-supply-bridged.brd, single-supply-bridged.sch]
2012-08-22 Updated BOM
    [Class D Amp v2 BOM.ods]
2012-08-23 Minor modifications to the v3.0 amplifier .brd file Added in George's Project Notebook
    [single-supply-bridged.brd]
2012-08-23 Changed 74LS126 to 74HC126 in BOM
    [Class D Amp v2 BOM.ods]
